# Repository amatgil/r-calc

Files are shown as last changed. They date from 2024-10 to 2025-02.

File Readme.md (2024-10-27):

# Calculadora de mà amb R

## Botons
- `p_`
- `q_`
- `d_`
- `_bern`
- `_binom`
- `_pois`
- `_nbinom`
- `_unif`
- `_norm`
- `0`
- `1`
- `2`
- `3`
- `4`
- `5`
- `6`
- `7`
- `8`
- `9`
- `+`
- `-`
- `*`
- `/`
- `^`
- `.`: Punt decimal
- `=`
- `Delete/Backspace`
- `Clear/On`
- `(`
- `)`
- `,`: Separador d'arguments de les funcions
- `Left`
- `Right`

## Layout preliminari
| bern   | p | q | d | Clear/On |
| binom  | 7 | 8 | 9 | Del      |
| pois   | 4 | 5 | 6 | +        |
| nbinom | 1 | 2 | 3 | -        |
| unif   | 0 | ( | ) | *        |
| norm   |   |   |   | /        |
|        |   |   |   | ^        |
|        |   |   |   | =        |

### Extra possibles
- `geom` 

## Internals
- Representació interna: matriu

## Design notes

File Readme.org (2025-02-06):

* Calculadora de mà amb R

** Botons
- =p_=
- =q_=
- =d_=
- =_bern=
- =_binom=
- =_pois=
- =_nbinom=
- =_unif=
- =_norm=
- =0=
- =1=
- =2=
- =3=
- =4=
- =5=
- =6=
- =7=
- =8=
- =9=
- =+=
- =-=
- =*=
- =/=
- =^=
- =.=: Punt decimal
- =\==
- =Delete/Backspace=
- =Clear/On=
- =(=
- =)=
- =,=: Separador d'arguments de les funcions
- =Left=
- =Right=

** Layout preliminari
Legenda: =Normal Shifted=

Nove versió (ara amb =Shift=)
(TODO: Make shift be ternary instead of binary ({A, B, C}) to add extra distributions and constats (pi, e, phi))

| Shift   | <-       | ->     | Bksp/On Clear |
| 7 p     | 8 q      | 9  d   | *  ^          |
| 4 bern  | 5 pois   | 6 norm | - /           |
| 1 binom | 2 nbinom | 3 unif | +             |
| 0       | (  .     | ) ,    | =             |

*** Extra possibles
- `geom` 

** Altres infos
El protocol de communicació amb la LCD segurament tocarà escriure'l a mà. La veritat és que sona no-irònicament força divertit.

- Analyze elf size: https://github.com/jedrzejboczar/elf-size-analyze
- Hardware consideration for AVR in general, part 1: http://ww1.microchip.com/downloads/en/Appnotes/AN2519-AVR-Microcontroller-Hardware-Design-Considerations-00002519B.pdf
- Capacitors, from phasors: https://www.electronics-tutorials.ws/filter/filter_1.html
- Parasitic capacitance: https://circuitdigest.com/tutorial/understanding-esr-and-esl-in-capacitors
- (Capacitor search terms: "second order filter", "ESL" "ESR")

** Manufacturing options
*** Basic
| Nom           | Preu | Funció                                | Link                                                                                 |
|---------------+------+---------------------------------------+--------------------------------------------------------------------------------------|
| ATMEGA328P-PU | 2.7€ | La part que calcula de la calculadora | https://www.digikey.es/en/products/detail/microchip-technology/ATMEGA328P-PU/1914589 |
| LCD           | 10€  | Output                                |                                                                                      |
| Mòdul i2c     |      | Tradueix protocol per la LCD          |                                                                                      |
| 4*5 botons    | 5€   | Input                                 | https://www.digikey.es/en/products/detail/adafruit-industries-llc/1010/7244937       |

També cal un =usb to serial adapter= (so that it can get programmed)

*** Scalable
- Very cheap MCU
- LCD with i2c translator
-

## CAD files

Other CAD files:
schematic/Calculadorra/Case.blend

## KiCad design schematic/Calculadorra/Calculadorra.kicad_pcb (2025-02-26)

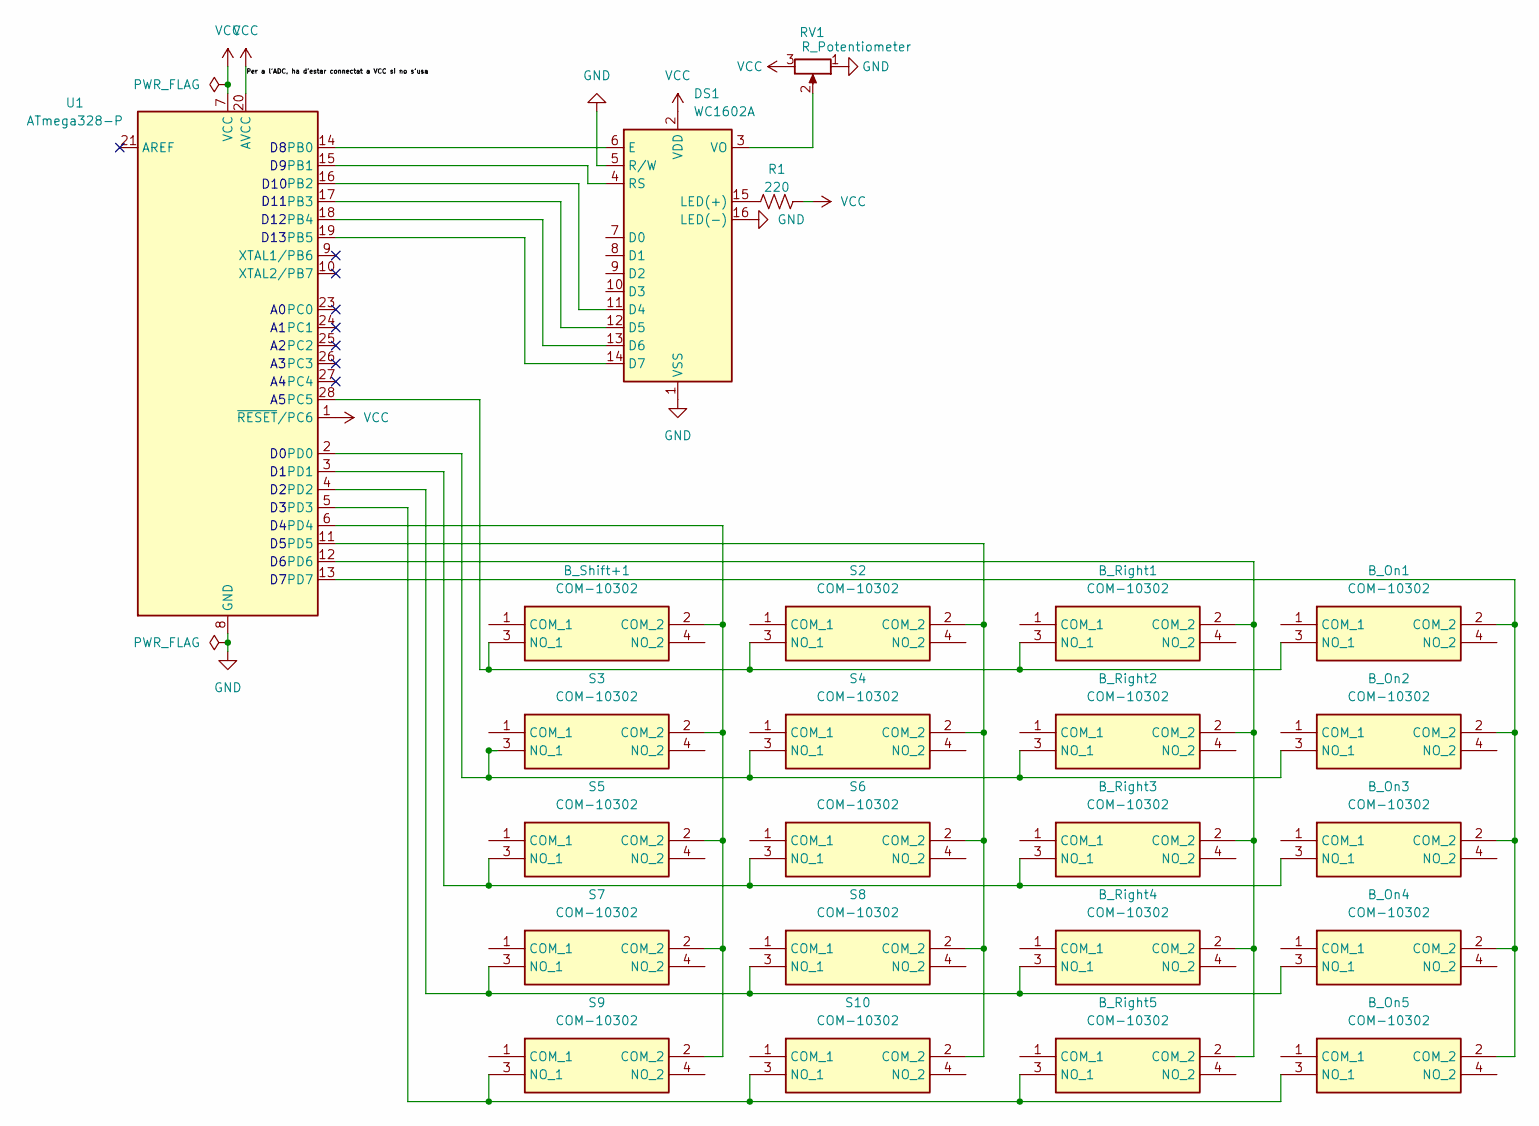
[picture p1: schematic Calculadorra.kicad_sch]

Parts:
B_On1, B_On2, B_On3, B_On4, B_On5: COM-10302; Button_COM10302; Mouser Part Number 474-COM-10302
B_Right1, B_Right2, B_Right3, B_Right4, B_Right5: COM-10302; Button_COM10302; Mouser Part Number 474-COM-10302
B_Shift+1: COM-10302; Button_COM10302; Mouser Part Number 474-COM-10302
DS1: WC1602A
R1: 220; R_LDR_4.9x4.2mm_P2.54mm_Vertical
RV1: R_Potentiometer; Potentiometer_ACP_CA6-VSMD_Vertical_Hole
S2, S3, S4, S5, S6, S7, S8, S9, S10: COM-10302; Button_COM10302; Mouser Part Number 474-COM-10302
U1: ATmega328-P; DIP-28_W7.62mm

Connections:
GND: DS1.1 (VSS), DS1.5 (R/W), DS1.16 (LED(-)), RV1.1, U1.8 (GND), U1.22 (GND)
unnamed: B_On1.2 (COM_2), B_On2.2 (COM_2), B_On3.2 (COM_2), B_On4.2 (COM_2), B_On5.2 (COM_2), U1.13 (PD7)
unnamed 2: B_On1.3 (NO_1), B_Right1.3 (NO_1), B_Shift+1.3 (NO_1), S2.3 (NO_1), U1.28 (PC5); also elsewhere on the board
unnamed: B_On2.3 (NO_1), B_Right2.3 (NO_1), S3.3 (NO_1), S4.3 (NO_1), U1.2 (PD0)
unnamed: B_On3.3 (NO_1), B_Right3.3 (NO_1), S5.3 (NO_1), S6.3 (NO_1), U1.3 (PD1)
unnamed: B_On4.3 (NO_1), B_Right4.3 (NO_1), S7.3 (NO_1), S8.3 (NO_1), U1.4 (PD2)
unnamed: B_On5.3 (NO_1), B_Right5.3 (NO_1), S9.3 (NO_1), S10.3 (NO_1), U1.5 (PD3)
unnamed: B_Right1.2 (COM_2), B_Right2.2 (COM_2), B_Right3.2 (COM_2), B_Right4.2 (COM_2), B_Right5.2 (COM_2), U1.12 (PD6)
unnamed 8: B_Shift+1.2 (COM_2), S3.2 (COM_2), S5.2 (COM_2), S7.2 (COM_2), S9.2 (COM_2), U1.6 (PD4); also elsewhere on the board
unnamed: DS1.11 (D4), U1.16 (PB2)
unnamed: DS1.12 (D5), U1.17 (PB3)
unnamed: DS1.13 (D6), U1.18 (PB4)
unnamed: DS1.14 (D7), U1.19 (PB5)
unnamed: DS1.6 (E), U1.14 (PB0)
unnamed: DS1.15 (LED(+)), R1.1
unnamed: DS1.4 (RS), U1.15 (PB1)
unnamed: DS1.3 (VO), RV1.2
unnamed: S2.2 (COM_2), S4.2 (COM_2), S6.2 (COM_2), S8.2 (COM_2), S10.2 (COM_2), U1.11 (PD5)
VCC: DS1.2 (VDD), R1.2, RV1.3, U1.1 (~RESET/PC6), U1.7 (VCC), U1.20 (AVCC)

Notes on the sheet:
D11
D13
D12
D10

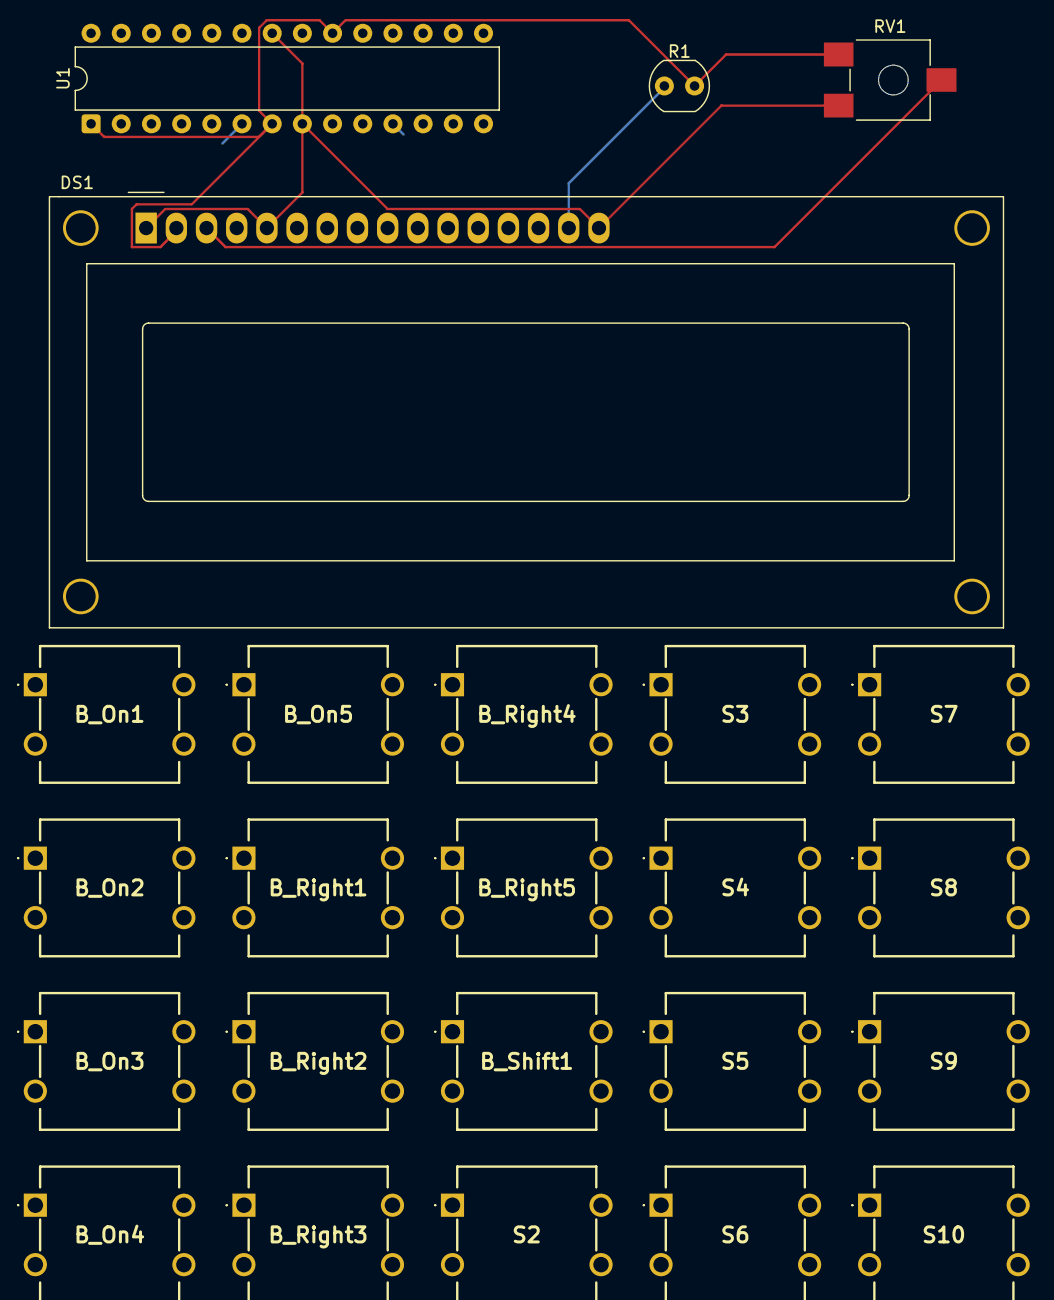
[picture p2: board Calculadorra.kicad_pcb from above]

Board: 4 copper layers, 24 parts (0 on the bottom side), 19 nets.

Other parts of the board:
B_Shift1: COM-10302; Button_COM10302

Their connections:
unnamed 2: B_Shift1.3 (NO_1); also elsewhere on the board
unnamed 8: B_Shift1.2 (COM_2); also elsewhere on the board

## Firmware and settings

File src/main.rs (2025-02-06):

#![cfg_attr(not(test), no_std)]
#![cfg_attr(not(test), no_main)]

use arduino_hal::{port::PinOps, prelude::*, *};
use hd44780_driver::{Cursor, CursorBlink, Display, DisplayMode};
use r_calc::{
    BufferType, Calculadora, Dist, Operacio, Paren, ShiftStatus, Token, VariantR, DISPLAY_HEIGHT,
    DISPLAY_WIDTH, LCD_INTERNAL_WIDTH, SCAN_MATRIX_HEIGHT, SCAN_MATRIX_WIDTH,
};
use ufmt::uwriteln;

//#[cfg(not(test))]
#[arduino_hal::entry]
fn main() -> ! {
    use arduino_hal::Delay;
    use hd44780_driver::HD44780;
    use r_calc::Enter;

    let dp = arduino_hal::Peripherals::take().unwrap();
    let pins = arduino_hal::pins!(dp);

    //let mut serial = arduino_hal::default_serial!(dp, pins, 57600);

    let mut calculadora = Calculadora::default();
    let mut held = false;

    // membrane pad
    let cols = [
        pins.d4.into_pull_up_input().downgrade(), // PD4
        pins.d5.into_pull_up_input().downgrade(), // PD5
        pins.d6.into_pull_up_input().downgrade(), // PD6
        pins.d7.into_pull_up_input().downgrade(), // PD7
    ];

    let mut rows = [
        pins.d3.into_output().downgrade(), // PD3
        pins.d2.into_output().downgrade(), // PD2
        pins.d1.into_output().downgrade(), // PD1
        pins.d0.into_output().downgrade(), // PD0
        pins.a5.into_output().downgrade(), // PC5
    ];

    // lcd
    let rs = pins.d9.into_output().downgrade();
    let en = pins.d8.into_output().downgrade();
    let d4 = pins.d10.into_output().downgrade();
    let d5 = pins.d11.into_output().downgrade();
    let d6 = pins.d12.into_output().downgrade();
    let d7 = pins.d13.into_output().downgrade();

    let mut delay = Delay::new();

    let mut lcd = HD44780::new_4bit(rs, en, d4, d5, d6, d7, &mut delay).unwrap();
    _ = lcd.reset(&mut delay);
    _ = lcd.clear(&mut delay);
    _ = lcd.set_cursor_visibility(Cursor::Visible, &mut delay);
    _ = lcd.set_cursor_blink(CursorBlink::On, &mut delay);

    let mut pressed: [bool; SCAN_MATRIX_HEIGHT * SCAN_MATRIX_WIDTH];

    loop {
        if !calculadora.is_cache_valid {
            calculadora.is_cache_valid = true;
            _ = lcd.reset(&mut delay);

            let inner = calculadora.display();
            let (top, bottom) = inner.split_at(DISPLAY_WIDTH);

            _ = lcd.set_cursor_pos(0, &mut delay);
            _ = lcd.write_bytes(top, &mut delay);
            _ = lcd.set_cursor_pos(LCD_INTERNAL_WIDTH as u8, &mut delay);
            _ = lcd.write_bytes(bottom, &mut delay);
            let lcd_cursor_pos = if calculadora.graphical_cursor >= DISPLAY_WIDTH {
                LCD_INTERNAL_WIDTH + (calculadora.graphical_cursor - DISPLAY_WIDTH)
            } else {
                calculadora.graphical_cursor
            };
            //uwriteln!(&mut serial, "REDRAWING {}", lcd_cursor_pos).unwrap_infallible();
            _ = lcd.set_cursor_pos(lcd_cursor_pos as u8, &mut delay);
            _ = match calculadora.shift_status {
                ShiftStatus::Si => lcd.set_cursor_blink(CursorBlink::On, &mut delay),
                ShiftStatus::No => lcd.set_cursor_blink(CursorBlink::Off, &mut delay),
            };
        }

        pressed = [false; SCAN_MATRIX_HEIGHT * SCAN_MATRIX_WIDTH];
        // read scan matrix
        for row in 0..SCAN_MATRIX_HEIGHT {
            rows[row].set_low();
            for col in 0..SCAN_MATRIX_WIDTH {
                if cols[col].is_low() {
                    pressed[row * SCAN_MATRIX_WIDTH + col] = true;
                }
            }
            rows[row].set_high();
        }

        // No pressing multiple keys allowed
        if pressed.map(|b| if b { 1 } else { 0 }).iter().sum::<Enter>() > 1 {
            continue;
        }

        let is_curr_pressed = pressed.iter().any(|&b| b);

        // If nothing is pressed, no need to change
        if let Some(pressed_idx) = pressed.iter().position(|b| *b) {
            match calculadora.currently_shown_buffer {
                BufferType::Tokens => {
                    use ShiftStatus as S;
                    if !held {
                        calculadora.is_cache_valid = false;
                        match (calculadora.shift_status, pressed_idx) {
                            (S::No, 0) => calculadora.add_token(Token::Digit(0)),
                            (S::Si, 0) => {}

                            (S::No, 1) => calculadora.add_token(Token::Paren(Paren::Open)),
                            (S::Si, 1) => calculadora.add_token(Token::DecimalPoint),

                            (S::No, 2) => calculadora.add_token(Token::Paren(Paren::Close)),
                            (S::Si, 2) => calculadora.add_token(Token::Comma),

                            (_, 3) => {
                                calculadora.compute();
                                calculadora.currently_shown_buffer = BufferType::Resultat;
                                _ = lcd.set_cursor_visibility(Cursor::Invisible, &mut delay);
                                _ = lcd.set_cursor_blink(CursorBlink::Off, &mut delay);
                            }
                            (S::No, 4) => calculadora.add_token(Token::Digit(1)),
                            (S::Si, 4) => calculadora.add_dist_tokens(Dist::Binom),

                            (S::No, 5) => calculadora.add_token(Token::Digit(2)),
                            (S::Si, 5) => calculadora.add_dist_tokens(Dist::NBinom),

                            (S::No, 6) => calculadora.add_token(Token::Digit(3)),
                            (S::Si, 6) => calculadora.add_dist_tokens(Dist::Uniforme),

                            (_, 7) => calculadora.add_token(Token::Op(Operacio::Add)),

                            (S::No, 8) => calculadora.add_token(Token::Digit(4)),
                            (S::Si, 8) => calculadora.add_dist_tokens(Dist::Bernoulli),

                            (S::No, 9) => calculadora.add_token(Token::Digit(5)),
                            (S::Si, 9) => calculadora.add_dist_tokens(Dist::Poisson),

                            (S::No, 10) => calculadora.add_token(Token::Digit(6)),
                            (S::Si, 10) => calculadora.add_dist_tokens(Dist::Normal),

                            (S::No, 11) => calculadora.add_token(Token::Op(Operacio::Sub)),
                            (S::Si, 11) => calculadora.add_token(Token::Op(Operacio::Div)),

                            (S::No, 12) => calculadora.add_token(Token::Digit(7)),
                            (S::Si, 12) => calculadora.add_token(Token::VariantR(VariantR::P)),

                            (S::No, 13) => calculadora.add_token(Token::Digit(8)),
                            (S::Si, 13) => calculadora.add_token(Token::VariantR(VariantR::Q)),

                            (S::No, 14) => calculadora.add_token(Token::Digit(9)),
                            (S::Si, 14) => calculadora.add_token(Token::VariantR(VariantR::D)),

                            (S::No, 15) => calculadora.add_token(Token::Op(Operacio::Mul)),
                            (S::Si, 15) => calculadora.add_token(Token::Op(Operacio::Pow)),

                            (_, 16) => calculadora.toggle_shift(),

                            (_, 17) => calculadora.cursor_back(),

                            (_, 18) => calculadora.cursor_advance(),

                            (S::No, 19) => calculadora.clear(),
                            (S::Si, 19) => calculadora.del_token(),

                            // Pressing a button with no defined Shift should reset shift
                            (S::Si, _unassigned_button) => calculadora.toggle_shift(),

                            _ => {} // unreachable if scan matrix is set up right
                        }
                    }
                }
                BufferType::Resultat => {
                    if !held && is_curr_pressed {
                        calculadora.is_cache_valid = false;
                        calculadora.currently_shown_buffer = BufferType::Tokens;

                        _ = lcd.set_cursor_visibility(Cursor::Visible, &mut delay);
                        _ = lcd.set_cursor_blink(CursorBlink::On, &mut delay);
                    } else {
                        held = false;
                    }
                }
            }
        }
        match (held, is_curr_pressed) {
            (true, false) => held = false,
            (false, true) => held = true,
            _ => {}
        }
    }
}

#[cfg(not(test))]
#[panic_handler]
fn panic(_: &core::panic::PanicInfo) -> ! {
    loop {}
}

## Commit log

2024-10-27 Update layout so it's 8*4+1 (aaa I need one extra button)
2024-11-08 It compiles and runs on the board! Yay
2024-11-09 Integrated! Minor logic bugs, but we're underway
    [main.rs]
2024-11-11 Use the second line instead of missing text (ignore tokens for now)
    [main.rs]
2024-11-11 Avoid panic when displaying
    [main.rs]
2024-11-11 Shift funcionality fully implemented, including button control
2024-11-11 Fixed shift, holding and added paren when dist is pressed
    [main.rs]
2024-11-15 Fix cursor not displaying when it was on the second line
    [main.rs]
2025-01-29 Add schematic
    [Calculadorra.kicad_pcb, Calculadorra.kicad_sch]
2025-02-06 Fix scan matrix for 5x4
    [Calculadorra.kicad_sch]
2025-02-06 Add arduino uno schematics to mega320p
    [Calculadorra.kicad_sch]
2025-02-06 Add a couple of shift buttons
2025-02-07 Pushed board specs (lmao i forgor)
2025-02-12 No idea what changed
    [Calculadorra.kicad_pcb, Calculadorra.kicad_sch]
2025-02-26 Disseny de la PCB i model 3D fet durant la Hacknight
    [Calculadorra.kicad_pcb, Calculadorra.kicad_sch, Case.blend]
2025-02-26 PCB amb nous botons, ja posarem díodes i cables en altres moments
    [Calculadorra.kicad_pcb, Calculadorra.kicad_sch]
